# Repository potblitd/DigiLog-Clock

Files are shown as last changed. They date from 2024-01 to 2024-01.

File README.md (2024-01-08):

<p align="center">
  
</p>

## Concept
There a quite a few articles about electronic projects using a grid arrangement of multiple analog clocks to form a mechanical digital clock such as [this one](http://hackaday.io/project/163582-digital-clock-made-of-analog-clocks). Even though they are visually pleasing with numerous rotating pointers and are definitely interesting engineering projects, these clocks require a lot of dual shaft stepper motors to display just one single number. Also, the use of such an arrangement doesn't allow a clean representation of all the 7-segements digits and the pointers that are not used for particular time displays will be hanging around leaving visible lines at random places. The *Concept* part describes the design and movement sequence of my own version of a digital clock composed by multiple analog clocks.

<p align="center">
  
</p>

### Idea
The main goal is to first design an interface with the fewest single-shaft rotating axes to properly display all 7-segment digits and then, to elaborate the most effective rotations sequence to create a counter. Before getting into the design part of the display, a few considerations need to be set based on the future electronic implementation part of this project.
+ For cost saving and program simplification, each axis will have **one rotating element**
+ Located on the same physical plane, the pointers can **not collide or overlap** with each other
+ Driven by servo motors, the rotating elements have a maximum of **180 degrees range**
<!--
<p align="center"> 
  <img src="images/DigiLog-design.svg" width="300" />
</p>
-->
### Design
First of all, to hide out-sticking pointers, the surrounding space outside the digit display will be covered. As the digital clock is displayed by rotating pointers, it is clear that one end of each segment should be attached to an axis. In this way, the arrangement with the least rotating elements that also meets the requirements set above is sketched below. Each element and its possibles position have been given a code combination to facilitate the movements sequence design and coding.
<!-- 
<p align="center">
   <img src="images/axes.svg" width="400" /> <br/><br/>
   <img src="images/digits.svg" width="600" />
</p>

 By observing the digits 0 to 9, an overview can be obtained of which segments are present for each number, their combinations and transitions. Having only 180 degrees angle of rotation available, three 90-degrees spaced positions have to be defined for each axis. The initial positions are already given from the 8 digit. For the blue pointers, a position completely outside the digit display is needed for a 1 and the one in between, covering the top horizontal segment, for a 2. Similarly from numbers 2 and 4, the rotation range for the green elements can be determined. This is further verified by the fact that both pointers never have to go outside the digit display to compose all the numbers. Digit 1 indicates that the yellow pointer needs one position outside the display and the upper left vertical segment for 0. The remaining two purple positions are simply found from any digits in the sequence. The space coverage for each element and their 3 possible positions are illustrated in the figures below. A label is given to each rotating point as well their positions in order to facilitate notations in the next section. -->

<p align="center">
   <br/><br/>
  
</p>

### Sequence
With the code name for each digit representation, the transition movements between them can are written down. For a conventional clock, transitions for counting up and displaying digit 0 from any number and to any number from 0 must be considered. Sometimes, not all the rotating elements can perform the necessary movements simultaneously due to possible collisions of two pointers. In this case, the rotations are executed consecutively in the shortest possible timeframe. 

<p align="center">
  
  &nbsp;&nbsp;&nbsp;&nbsp;&nbsp;&nbsp;&nbsp;&nbsp;&nbsp;&nbsp;
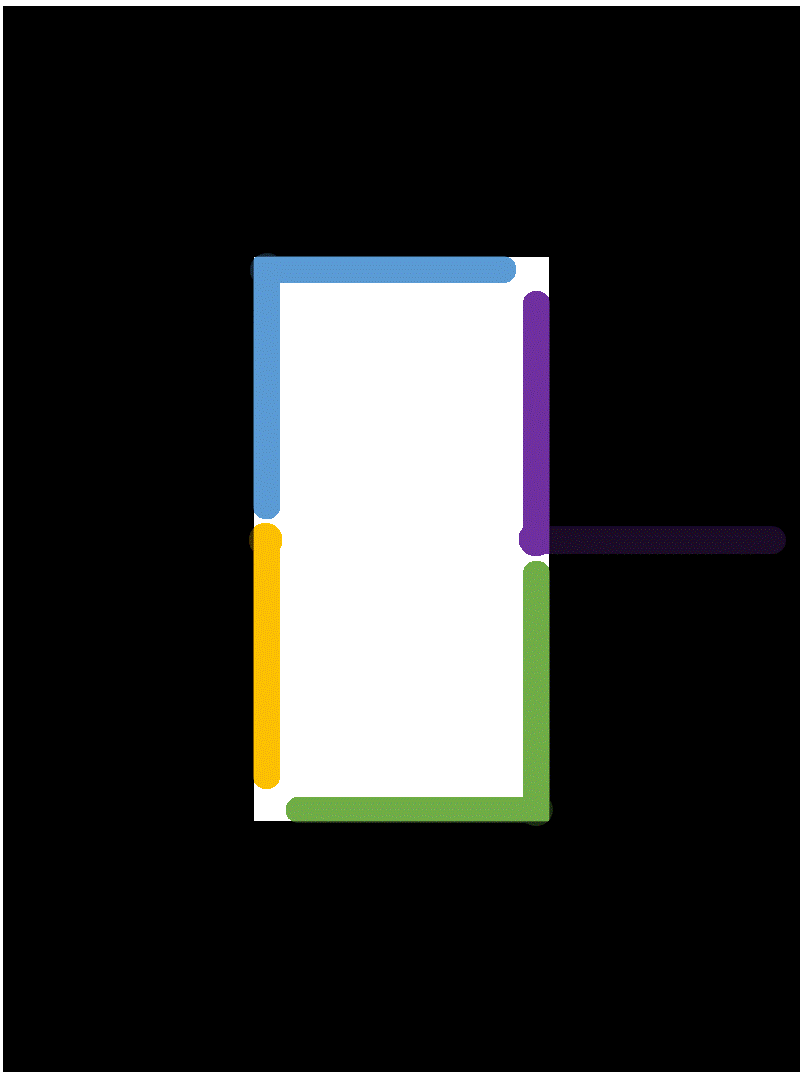
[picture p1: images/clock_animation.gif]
  
</p>

## Implementation
### Components
For the electronic part, which basically controls the movements of the rotating elements, almost only breakout modules are used in order to keep the assembly and programming simple. The main components for one display are listed below.
+ 4 x SG90 servo motor
+ PCA9685 PWM driver
+ 5V2A DC power supply
+ ESP8266 D1 mini dev board
+ DS3231 RTC module

<p align="center">
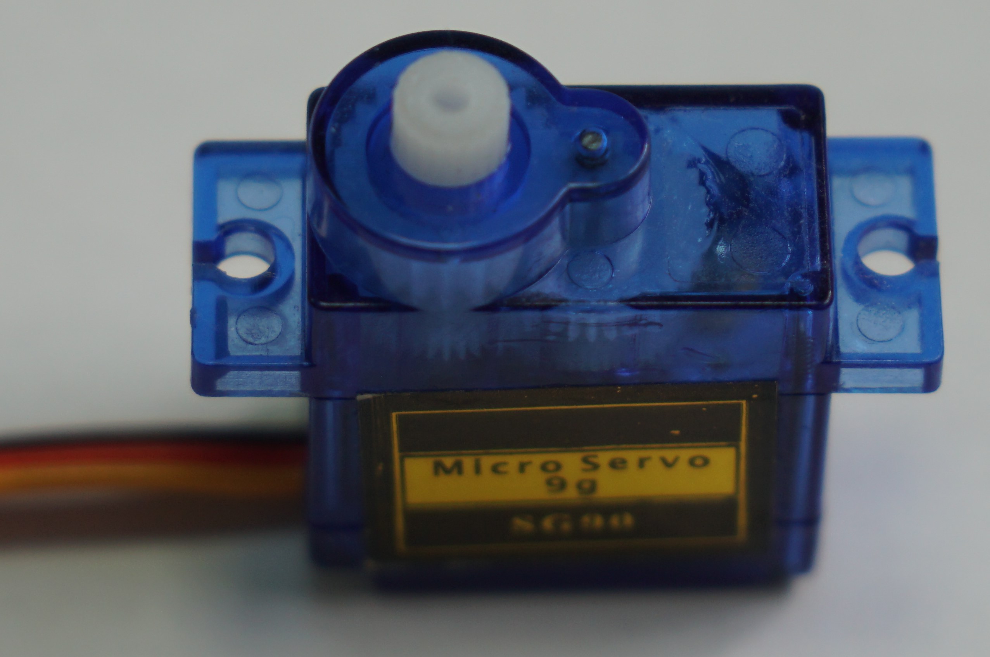
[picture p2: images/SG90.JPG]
  
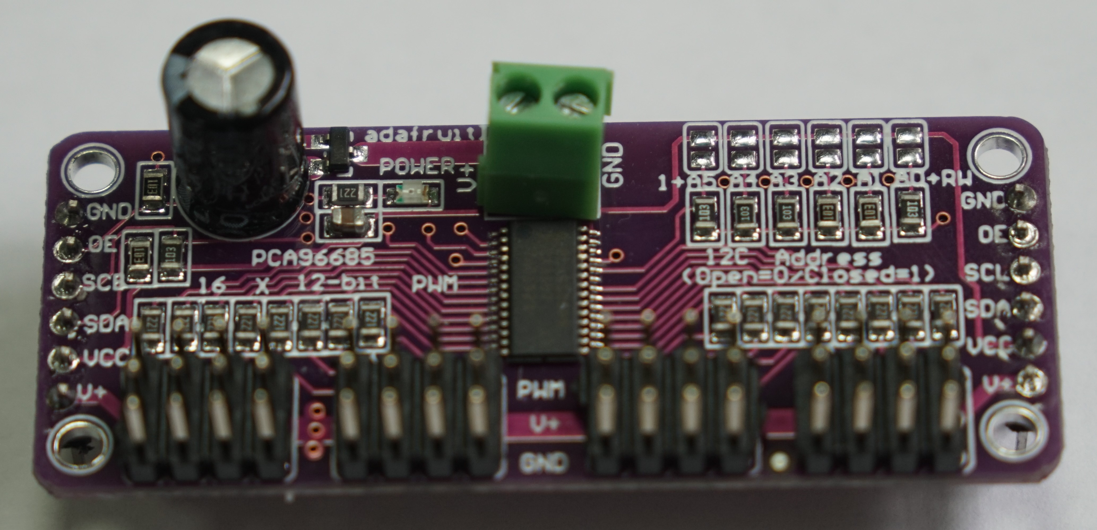
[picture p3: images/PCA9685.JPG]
  
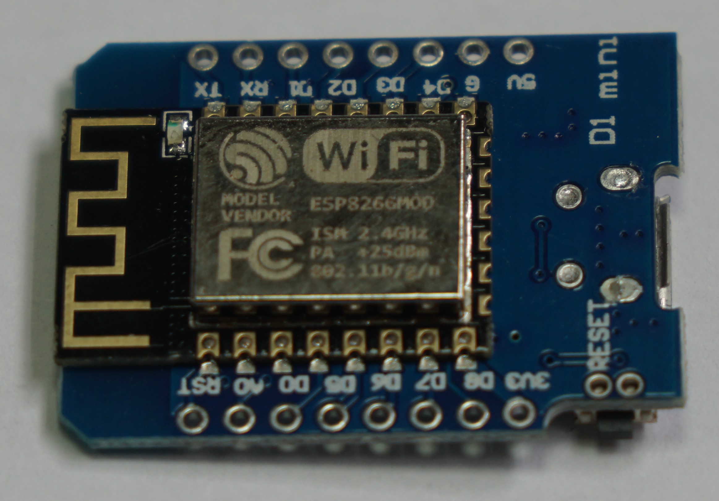
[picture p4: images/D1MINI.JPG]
  
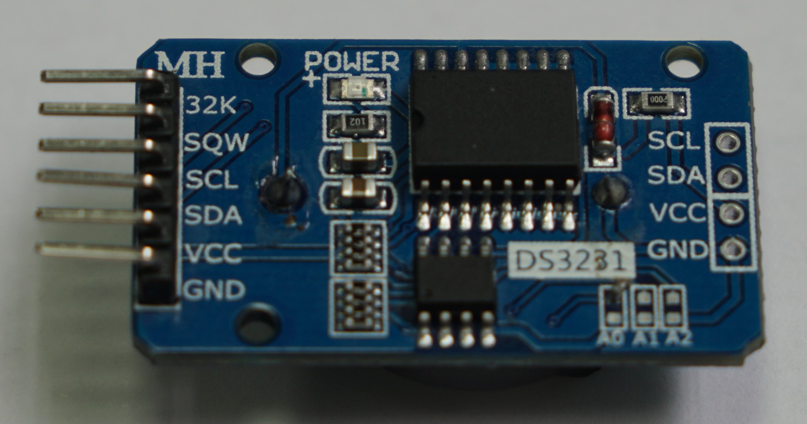
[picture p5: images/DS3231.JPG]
  
</p>

The commonly used SG90 servo motor is chosen for this project as it is small, light and cheap. The torque has no particular importance here but its angular speed, which is about 0.15s/90 degrees, is crucial to make sure a digit transition is possible every second. In order to drive multiple of these SG90s simultaneously, a PCA9685 16-Channel Servo/PWM driver is used. It provides the current-demanding motors with separated 5V from the external DC power supply and is controlled through an I2C interface which is communicated from the D1 mini. Finally, a real time clock module is included in the system to achieve good time accuracy.

### Schematics
The servo motors consuming lots of current, their voltage is provided through a barrel connector with the external 5V DC power supply cable. The presence of this voltage is indicated by a blue LED. If, additionally the USB cable is connected to the D1 mini, i.e. for programming the ESP8266, the switch should be positioned accordingly. In either case, VCC of 3.3 volts is generated by the internal LDO of the D1 mini and is indicated by a yellow LED. <br/>
The D1 mini microcontroller communicates with both the PWM driver and the real-time clock through an I2C interface. Four push buttons, used for start & stop, reset and setting the time, are connected to the GPIO pins D5, D6 and D7 which are pulled high internally, and D8 which is pulled low on the ESP8266 module board. If more than 16 servo motors are used in a setup, another PCA9685 driver can be connected via the additional pin headers P1 or P2. 

<p align="center">
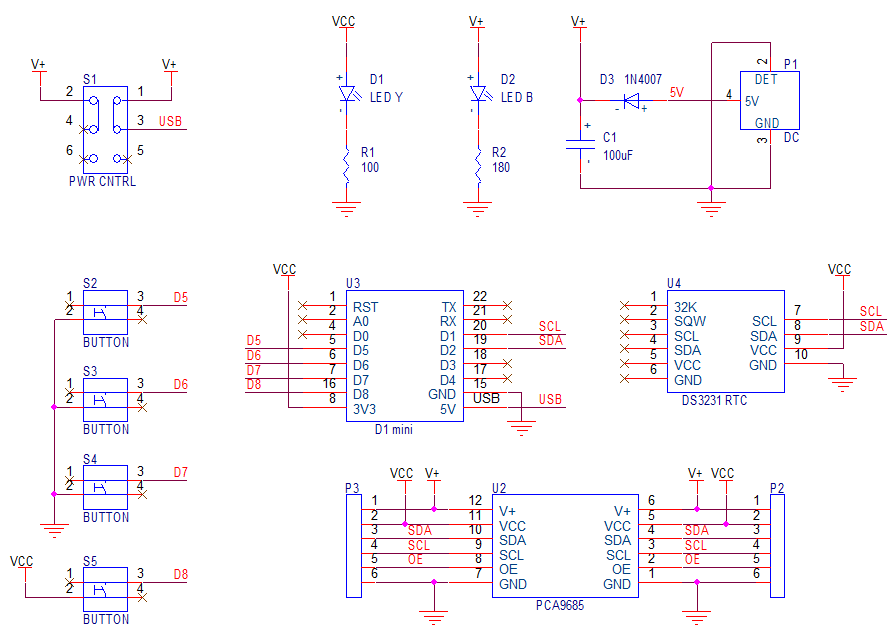
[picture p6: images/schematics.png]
  
</p>

### PCB
The PCB has the same size as the assembly outline so it can be fixed to the mounting plates with M3 standoffs. All the components are installed on the top layer of the board. It is also possible to solder the switch, button and LEDs on the bottom layer for a different mounting configuration. Modules D1 mini, DS3231 RTC and PCA9685 PWM driver are simply plugged into their corresponding female pin headers so that they can be removed or inserted easily.

<p align="center">
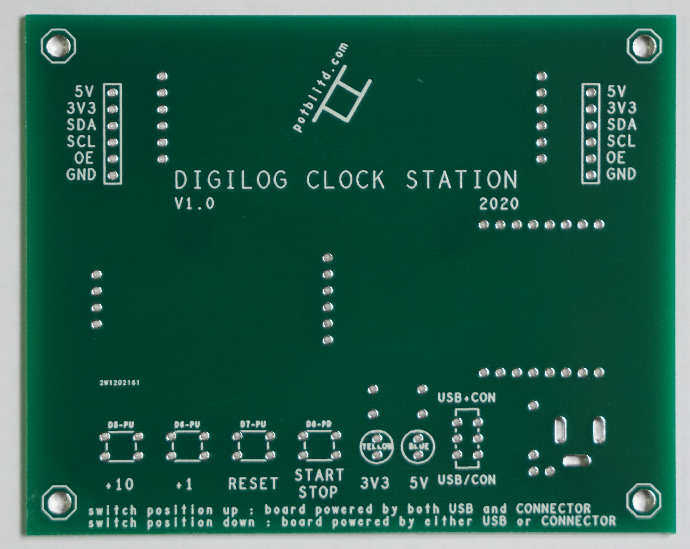
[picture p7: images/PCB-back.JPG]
  
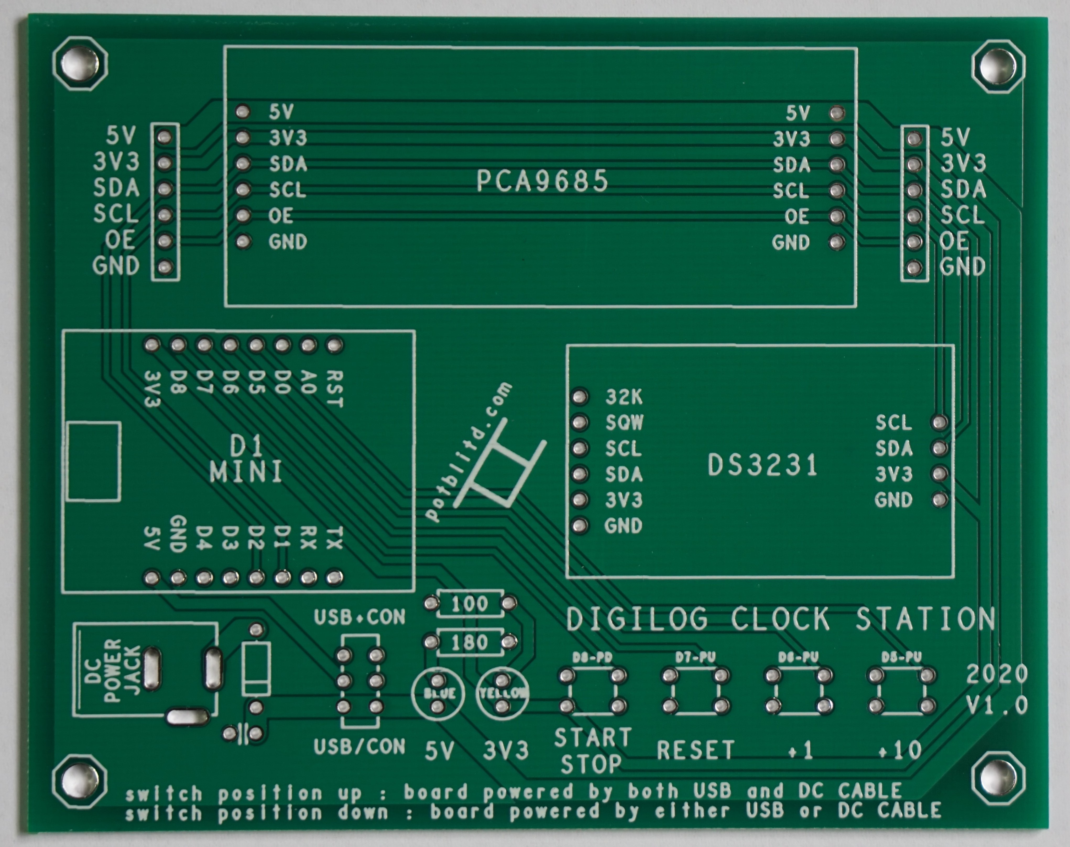
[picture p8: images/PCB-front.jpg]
  
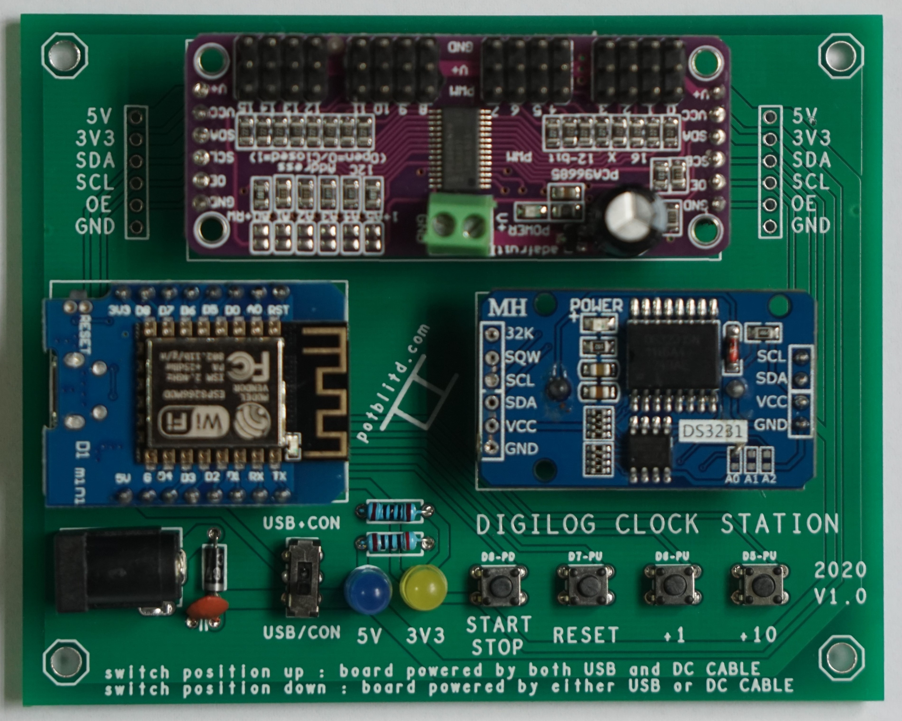
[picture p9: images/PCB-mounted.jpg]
  
</p>

### Display
In the [Concept](#concept) section, the arrangement of the rotating axes has already been established. Now, the positions of the servo motors are determined so as to set the smallest distance between their shafts. For this, they are tilted at 45 degrees separating their interaxial distance by 20 mm. In this configuration, multiple single digits can be arranged next to each other to form an hour-minute-second clock. <br>
For this project, the prototype assembly incorporates 8 servos allowing the composition of 2 digits. The outline dimensions are chosen so that the rotating pointers should never exceed the border. Both displays are placed 20 mm apart to avoid interfering each other. This results in an outline size of 100 mm by 80 mm. To hide the pointers turning outside of the digit display, a front plate is placed on top.

<p align="center">
  
</p>

### Mechanical parts
The mechanical parts for the assembly were designed in [Tinkercad](https://www.tinkercad.com/). One plate is used to precisely mount the 8 servo motors and another plate as the front cover. Both plates can be held together by fixing M3 screws in the corners. For the design of the rotating elements, the left pointers had to be higher than the right ones because they overlap with each other in the space between the digit displays.

<p align="center">
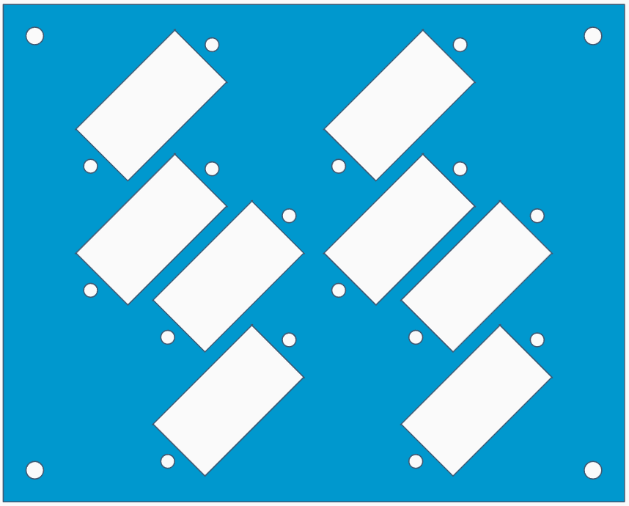
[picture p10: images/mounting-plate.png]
  
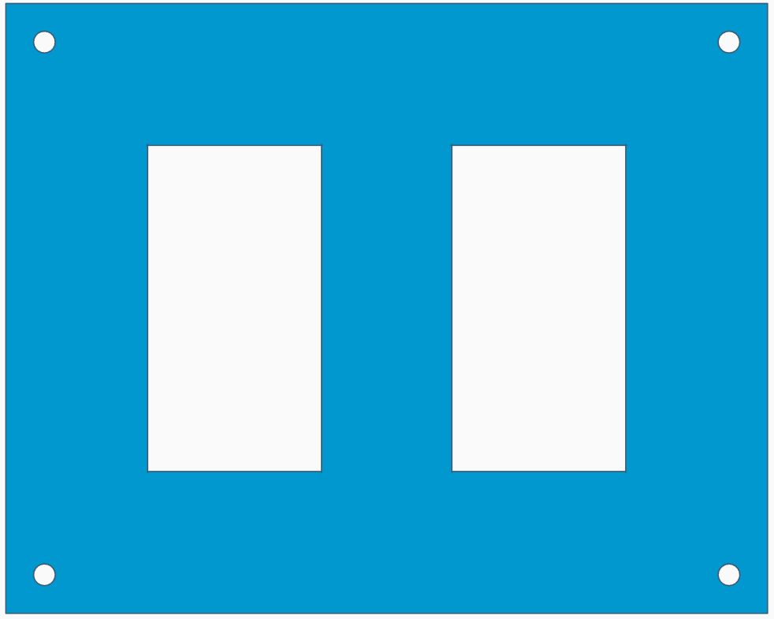
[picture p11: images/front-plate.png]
  
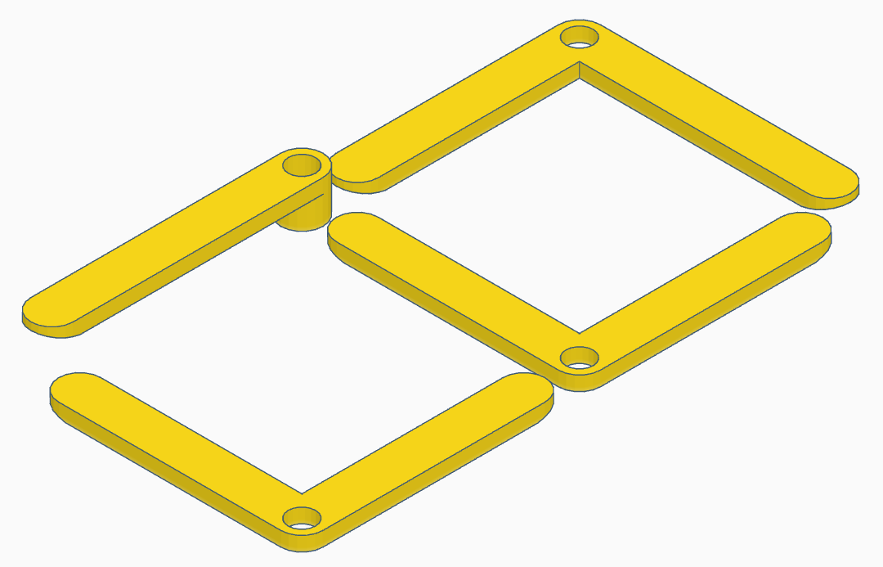
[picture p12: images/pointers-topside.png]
  
  <!-- <img src="images/assembly.png" height="200" /> -->
  <!--  <img src="images/assembly-side.png" height="150" /> -->
  <!-- <img src="images/assembly-front.png" height="200" /> -->
</p>

### Assembly
The 8 servo motors are inserted into their respective holes in the mounting plate and are fixed with small M2 screws. Then, the pointers can be positioned on the turning gear of the servos by sliding them on like a hat. This design is not exactly fitting so the pointers are not perfectly aligned with each other. After soldering all the components to the PCB, it is mounted onto the plates. In this configuration, the PCB is facing outwards where the SG90 cables go around the edges to connect into the PWM driver. By turning the PCB inwards, the connection cables stay inside the border outline, forming a more compact and closed assembly.

<p align="center">
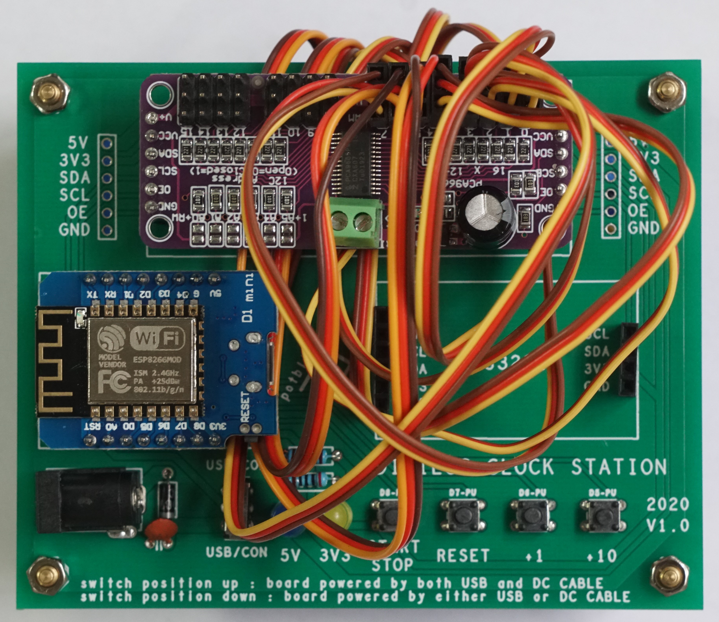
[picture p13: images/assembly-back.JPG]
  
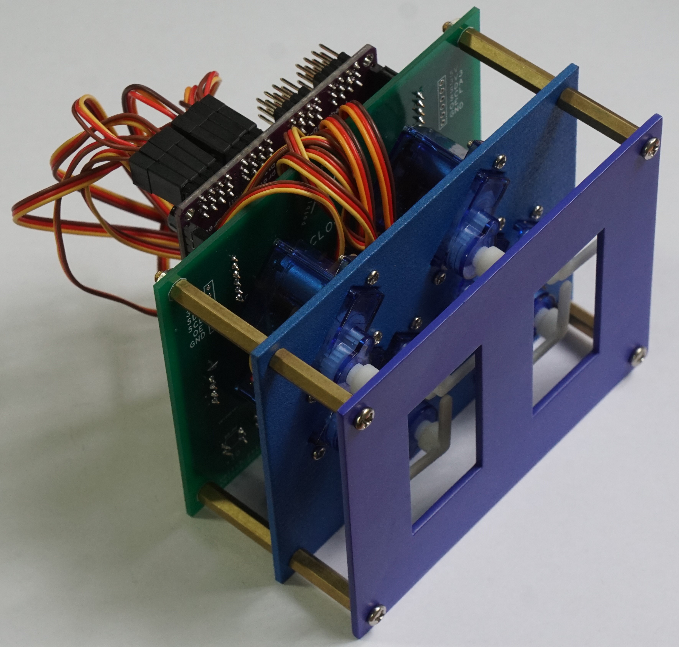
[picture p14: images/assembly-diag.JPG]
  
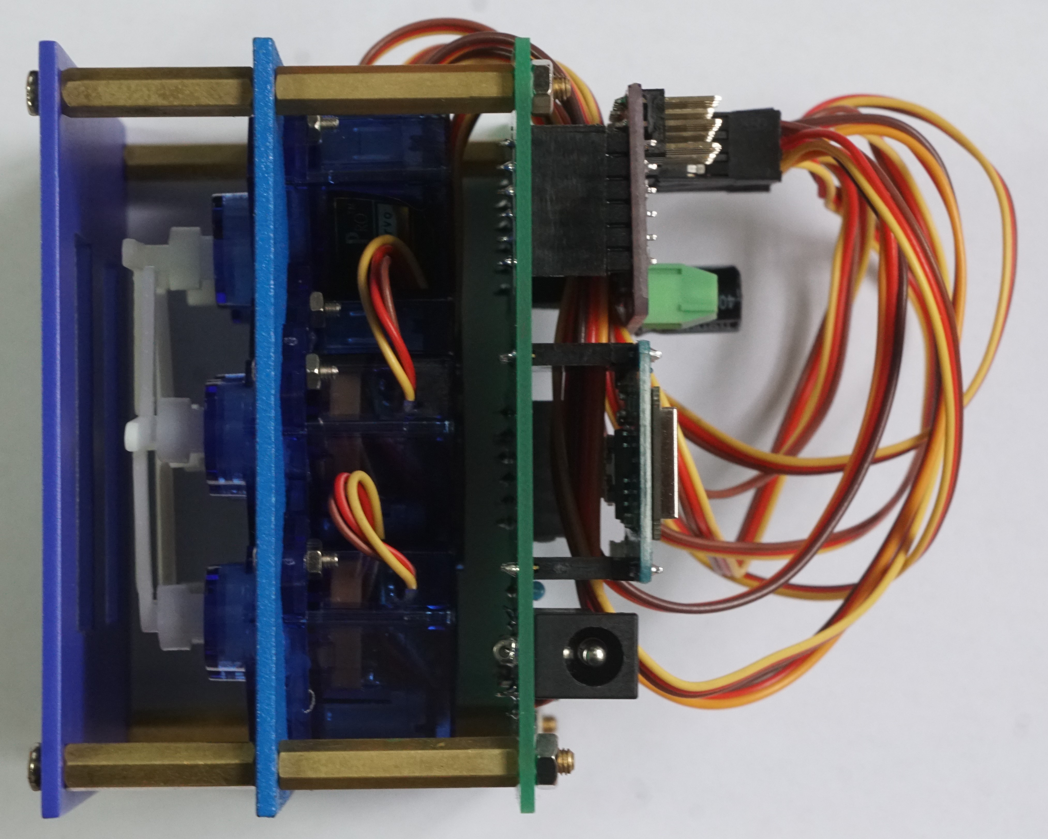
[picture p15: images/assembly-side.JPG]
  
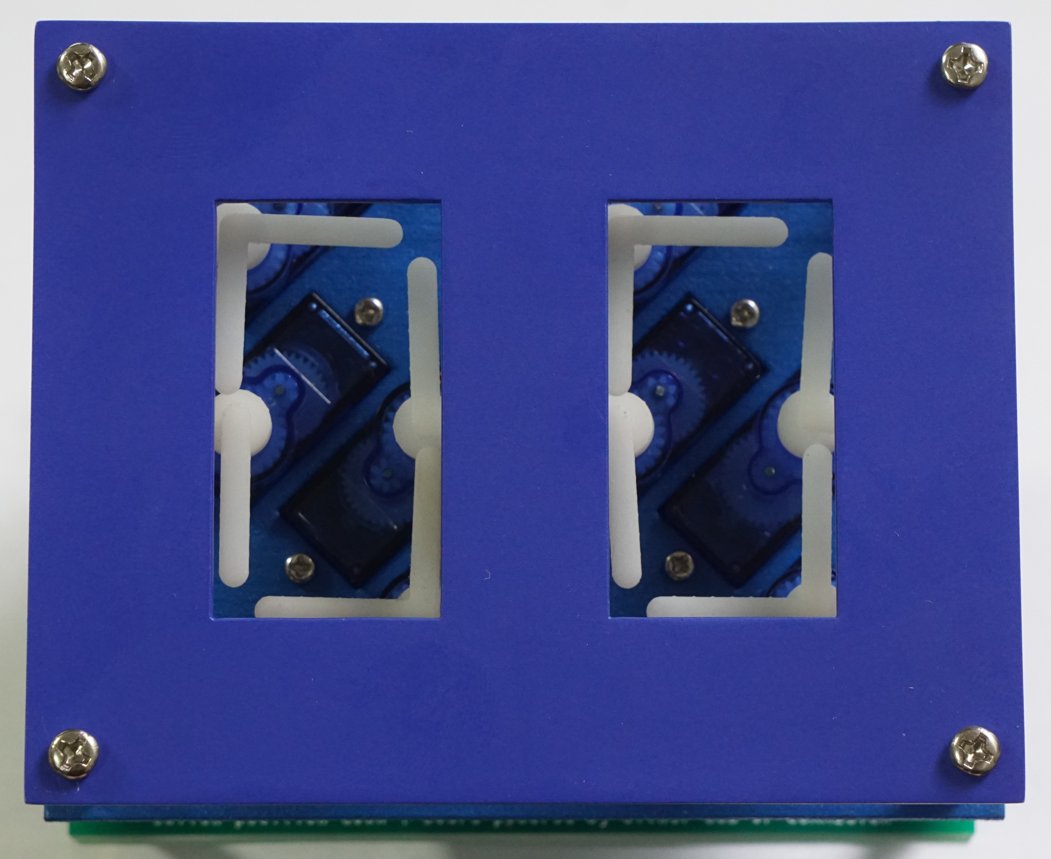
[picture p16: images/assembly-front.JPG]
  
</p>

### Code
In the Arduino program, the positions for each rotating element is configured so that they align as straight as possible. Due to some fabrication inaccuracies and angle precision limitations, not all the pointers could be smoothly aligned here. For the rest of the code, each transition is defined by the current digit and the next one based on the [sequence](#sequence). The D1 mini checks the current time from the DS3231 RTC and updates the digits on the display.

<p align="center">
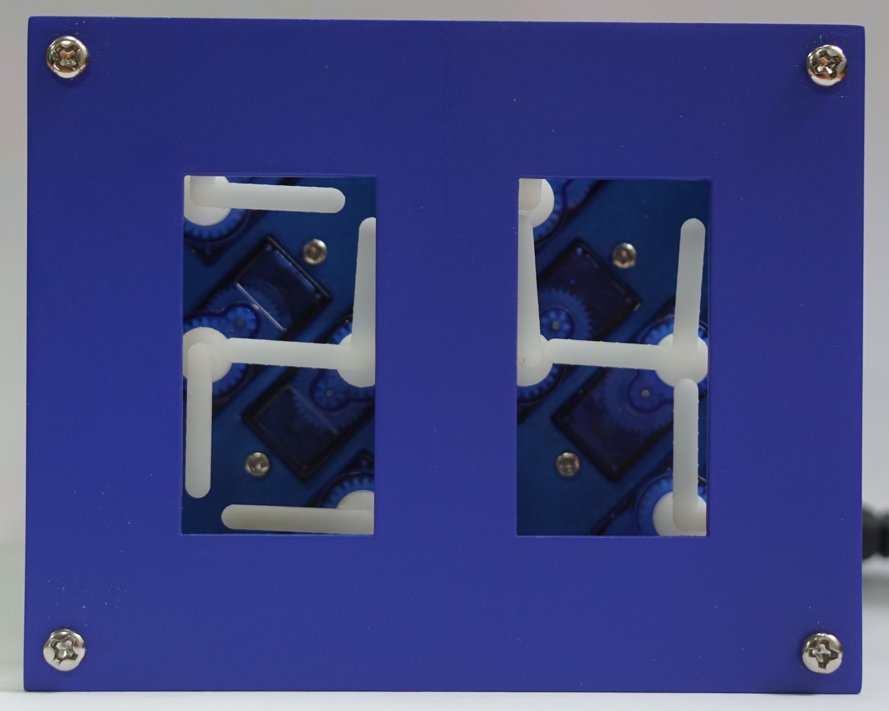
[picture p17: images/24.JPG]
  
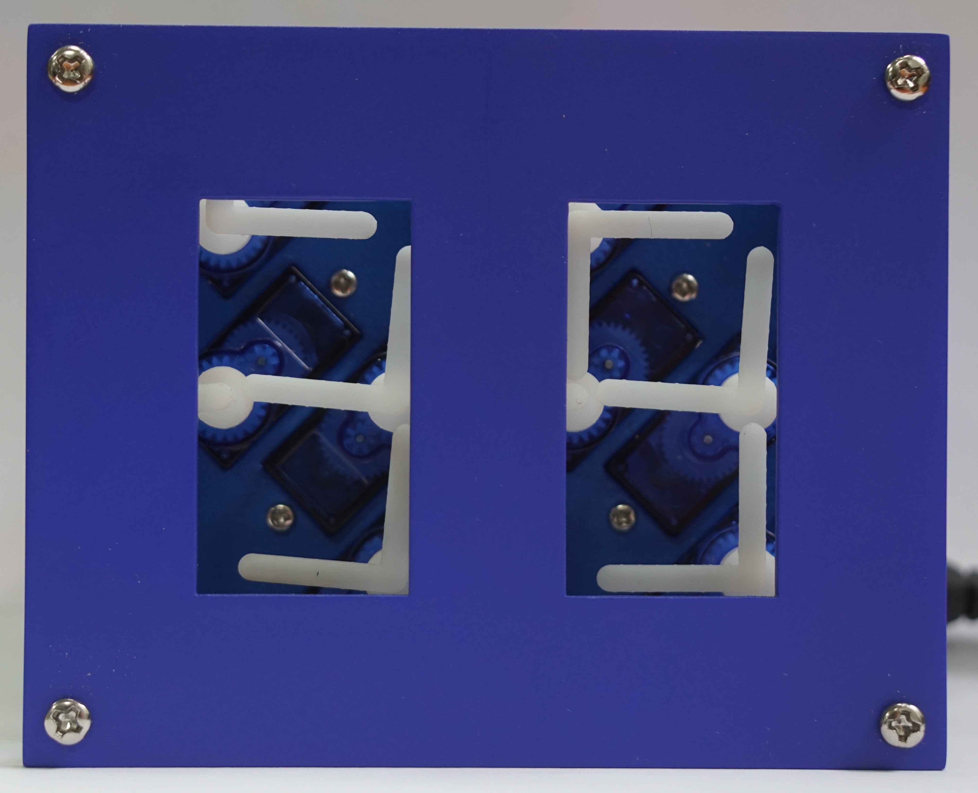
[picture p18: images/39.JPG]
  
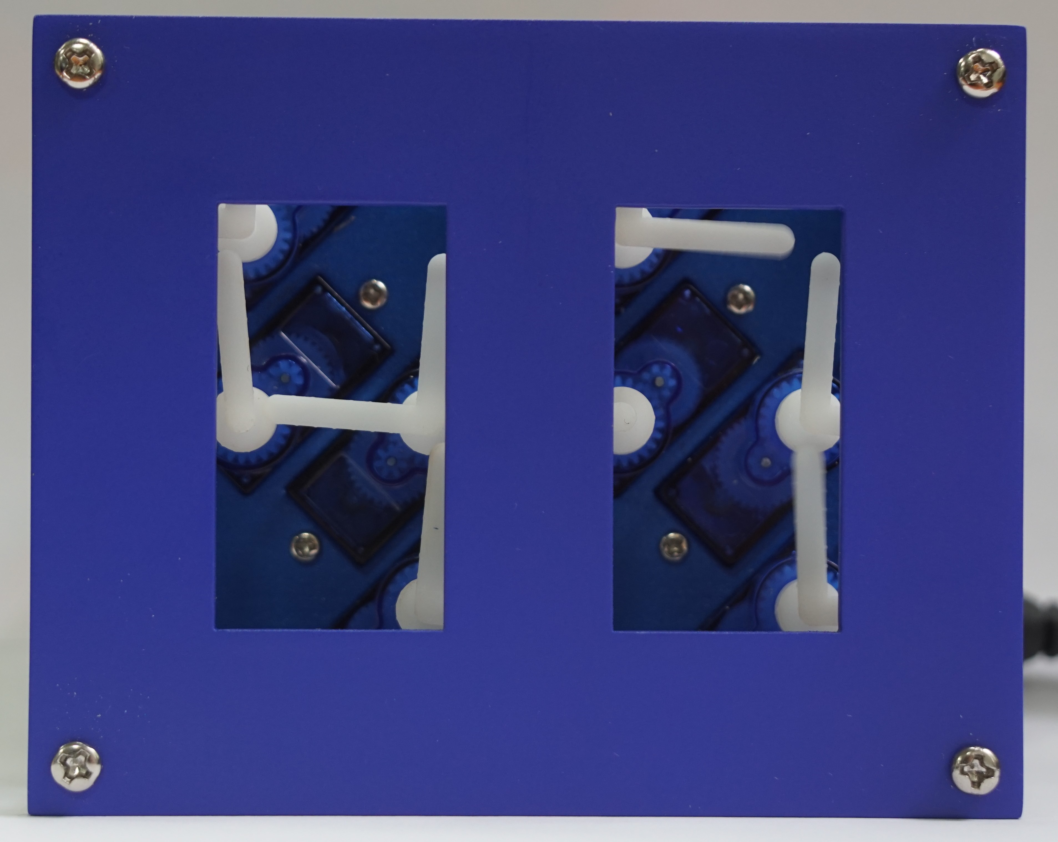
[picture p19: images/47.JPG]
  
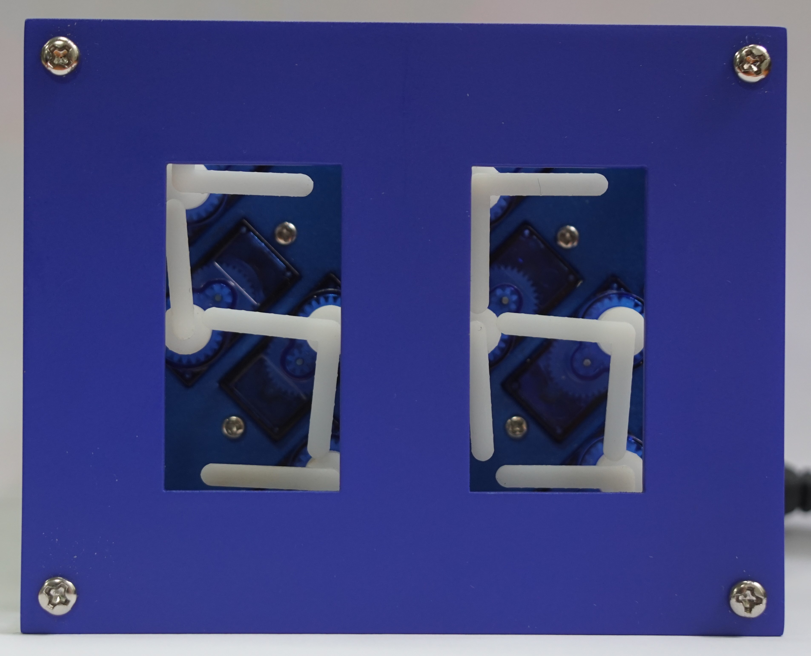
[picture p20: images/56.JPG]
  
</p>

### Cost
Electronic parts, i.e. PCB, modules, components to solder and servo motors costed about 80 RMB. The 3D printed mechanical parts with mounting screws and standoffs were 285 RMB altogether which gives a total price of 365 RMB (51.39 USD).

### Future improvements
The prototype assembly accomplishes its proof-of-concept perfectly fine, the servo transitions are fast and precise enough to beautifully display digits without collisions between pointers. However, there a few improvements to note for the code or for a future version.
+ To actually act as a clock and display the time, there should be at least 4 digits for minutes and hours. Having another pair of digits for the seconds could also be considered but each servo movement is noisy and can be bothering. Up to 16 servos can be driven by the PCA9685 and so, one PCB is sufficient.
+ The corners of the mechanical plates can be rounded to cover only the rotating pointers and thus reducing the size. This would also give the clock a better aesthetic.
+ Reading the digits requires a direct line of sight on the assembly because the front plate can hide the pointers when observing the clock from an angle. This can easily be corrected by mounting the front plate as close as possible to the pointers.
+ The four buttons on the back of the PCB could be implemented to add other features such as manual time setting, stopwatch, button-press counter or days/hours down-counter.
+ With the on-board ESP8266 WiFi chip, the clock could display live number fetched from the internet or from another device, such as a weather station.
+ Use laser cutting for the fabrication of the mechanical parts to reduce costs and get better accuracy.

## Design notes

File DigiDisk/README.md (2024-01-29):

<p align="center">
  
</p>

### Idea
This updated version of the DigiLog clock, called 'DigiDisk', is meant to improve the previous design but also change a few aspects to meet the following requirements :

+ Use cheap and easily available components
+ Simple setup with as little parts as possible
+ Full clock, meaning at least 4 digits
+ Use overlapping disks to avoid collision of sharp edges and accelerate digit transitions
+ Ditch the WiFi, embrace minimal MCUs
+ Fully assembled PCB (no modules)
+ Finish version, no more ugly prototypes
+ USB type-C power and programming

### Design
Having overlapping disks with marked pointers instead of bar elements involved changing the 4 axes positions and pointers arrangement, and set the disk layer order to draw all 10 digits. With the code names, each digit can be defined by its disks positions. Since the rotating elements are overlapping each other, there is no need to plan the sequence diagram as done for the first version. This significantly simplifies the coding parts later on.

<p align="center">
   <br/><br/>
  
  &nbsp;&nbsp;&nbsp;&nbsp;&nbsp;
  
</p>

### Components
The servo motors are driver by the PCA9685 PWM controller used previously and the time is fetched from the common PCF8563 real-time clock. As the microcontroller of the system only needs to write and read with the two other chips through I2C, the ATtiny402 is very suitable (and my fav). The servo motors have been upgraded to the MG90S as they are less noisy and their motion is more smooth and precise without a dramatic price increase. For programming the ATtiny over USB, the CH340C is added as it has a simple footprint (SOP-16) and does not require an external oscillator. 

+ ATtiny402 microcontroller
+ CH340C USB to serial
+ PCF8563 real-time clock
+ PCA9685 PWM driver
+ 16 x MG90S servo motor

### Schematics
The system is powered through a USB-C port (on a breakout board) and its status is indicated by a blue LED. For the 16 servo motors, the power supply must be able to provide at least 18W. Programming the ATtiny402 is accomplished through the CH340C chip with the schottky diode between RX and TX to allow UPDI. Somehow, this setup works even without the pull-down resistors on the CC signals, which reduces components and extra connections. The RTC chip has a CR1220 coin cell as an auxilliary power source to keep the time running while unplugged from the USB-C connector. As only one PCA9685 driver is required, its i2C address is hardwired to the default value. 

<p align="center">
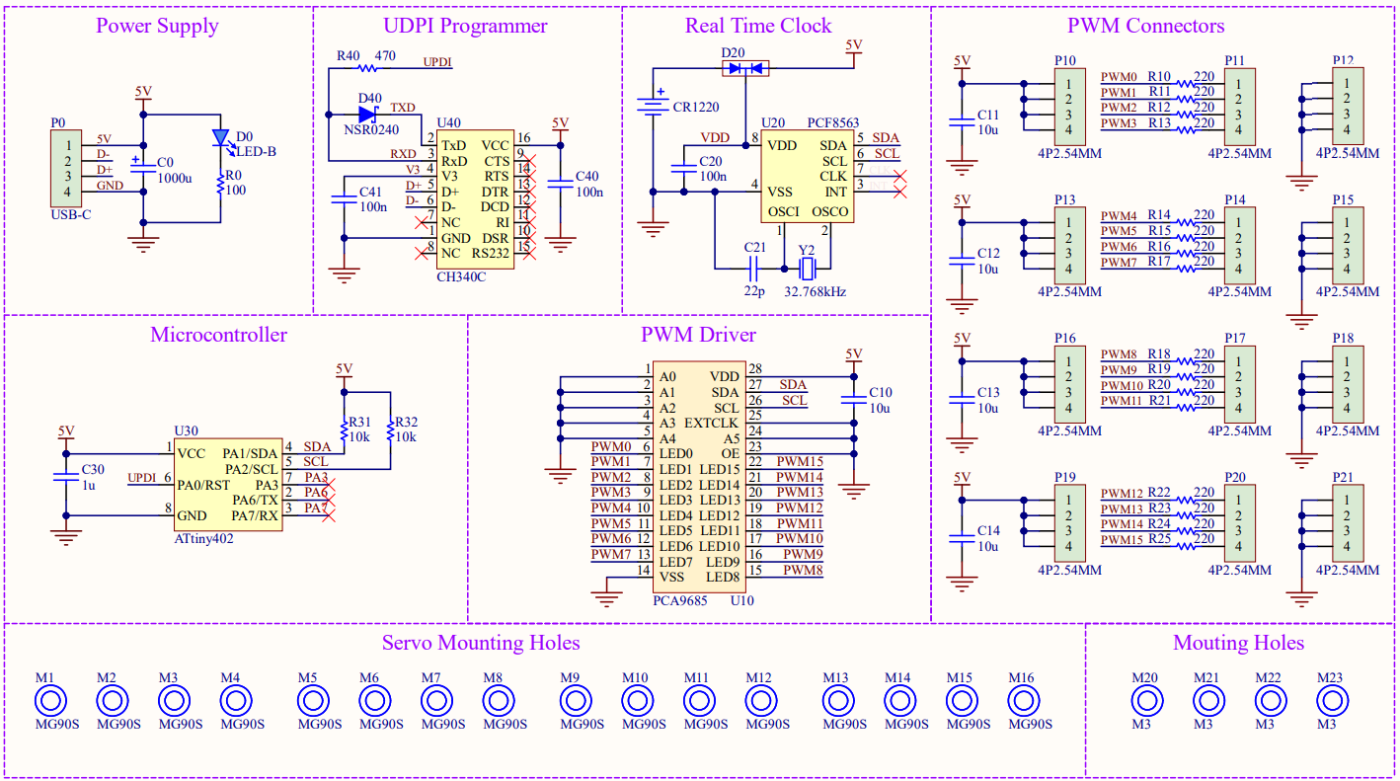
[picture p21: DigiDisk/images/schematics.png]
  
</p>

### Display
With the axes position slightly changed from the previous version, the servo also needed to be adjusted but the idea remains the same. In this configuration, two digits must be separated by at least 20mm. The front plate covers the unwanted pointers.  

<p align="center">
  <br/><br/>
  
</p>

### PCB
The board not only integrates all the electronic components, but also includes the mounting holes for the servo motors. In this way, no additonal mounting plates must be manufactured. The outline of the PCB is 80mm high by 180mm wide.

<p align="center">
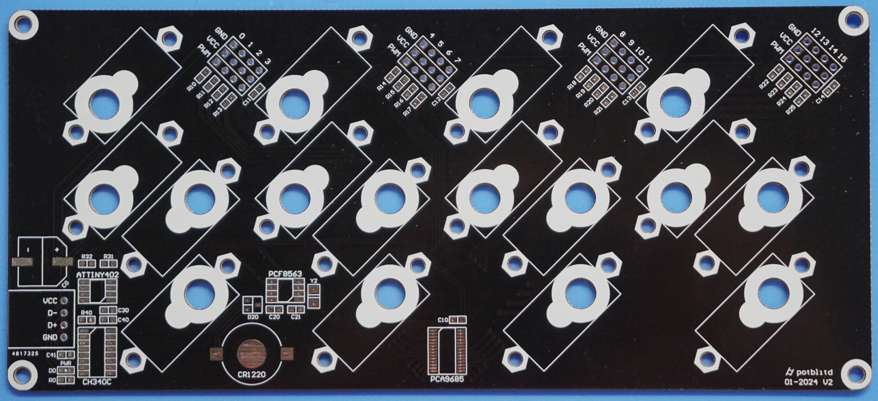
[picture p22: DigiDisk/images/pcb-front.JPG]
  
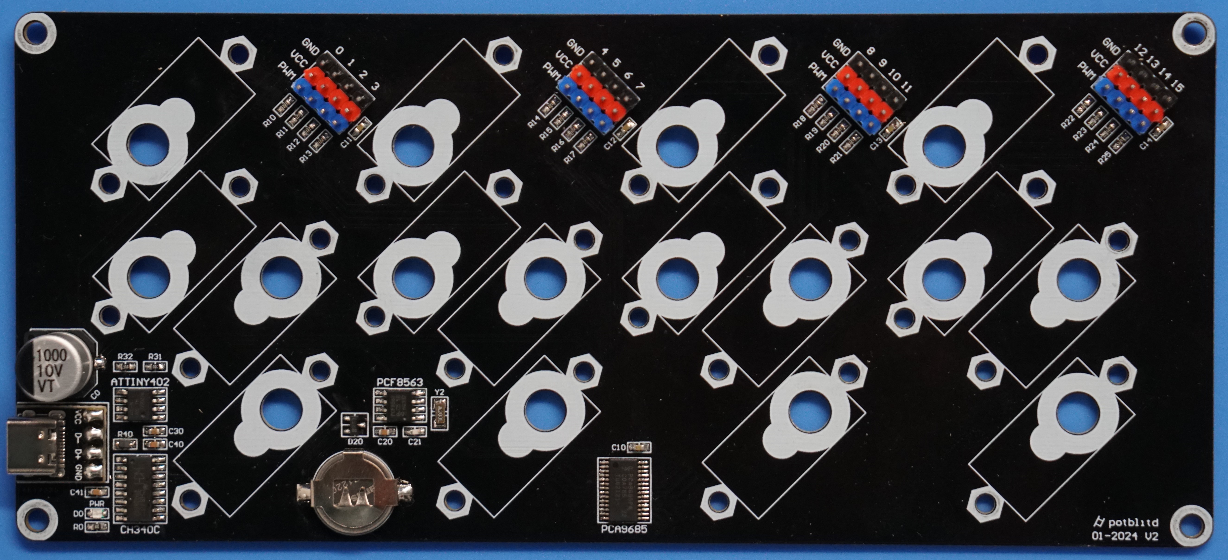
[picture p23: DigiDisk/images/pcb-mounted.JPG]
  
</p>

### Mechanical parts
Since the PCB acts as the mounting plate, only the rotating disks and the front plate must be manufactured. The disks are actually made from thin PCBs with silkscreen pointers as the thickness and material is very suitable. For the front plate, a 1mm PVC board was cut and painted black.

<p align="center">
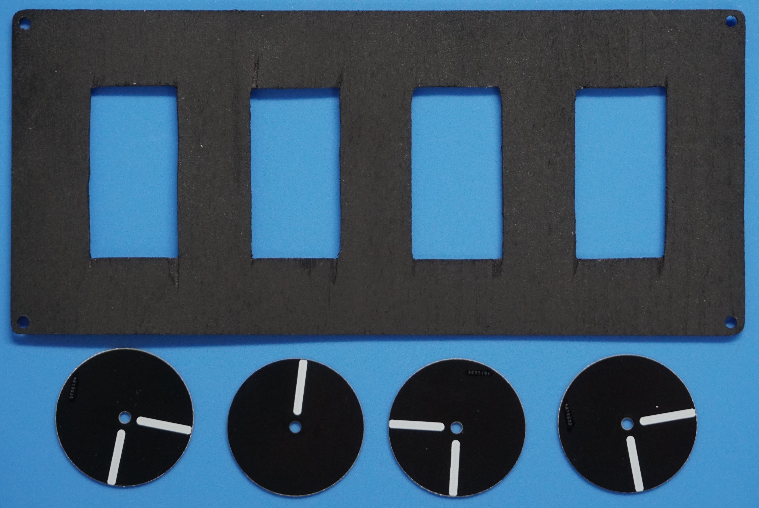
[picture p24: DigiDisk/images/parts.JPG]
  
</p>

### Assembly
All 16 servo motors are mounted to the base PCB with 9mm spacers and long screws. The precise mounting of the servos is crucial to avoid the rotating disks rubbing each other. With 0.8mm thick PCBs for the disks, they are overlaying each other through 1mm spacers, keeping the total height only a little over 5mm. The front plate not being perfectly falt, is mounted on top of the base PCB with 6mm spacers in the corners. 

<p align="center">
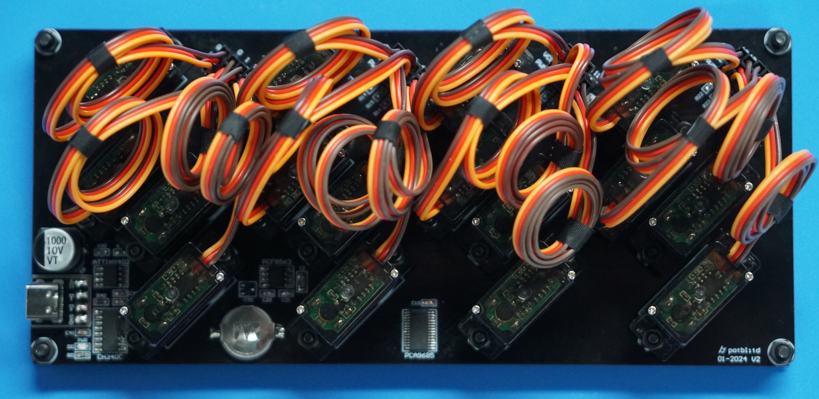
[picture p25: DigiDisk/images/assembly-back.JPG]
  
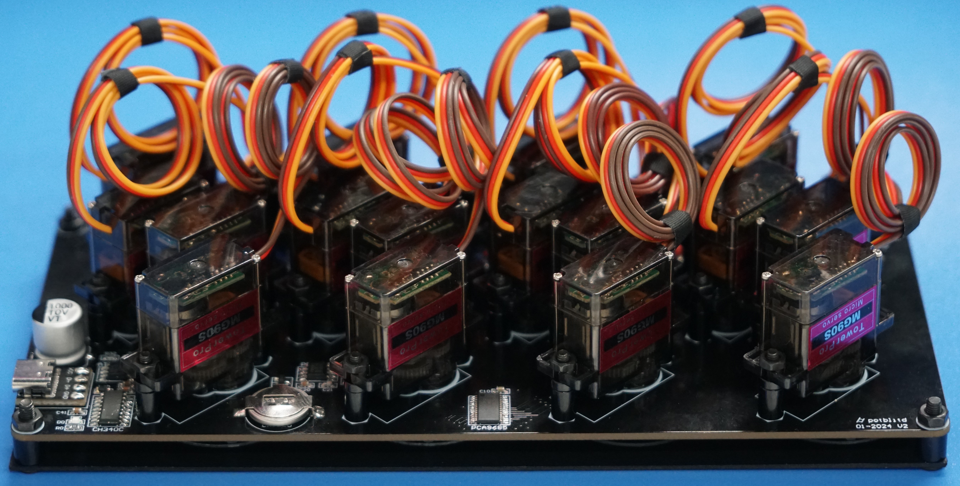
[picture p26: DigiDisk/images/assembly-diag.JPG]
  
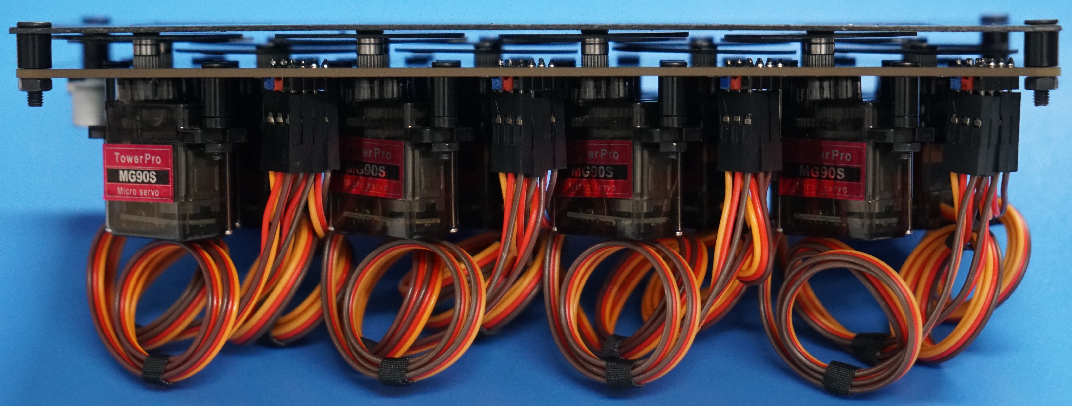
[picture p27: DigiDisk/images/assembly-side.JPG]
  
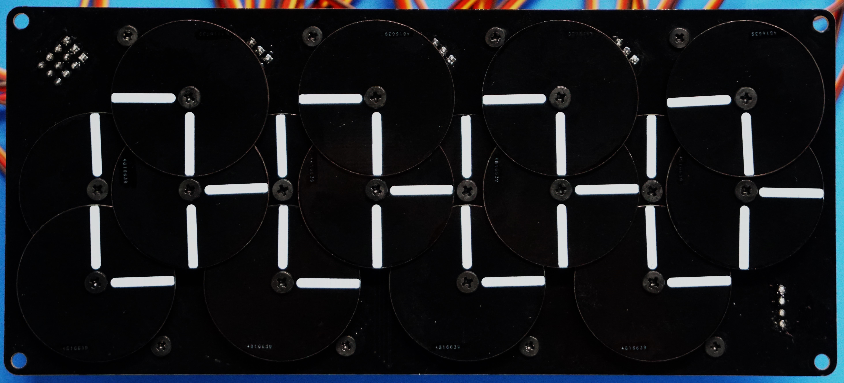
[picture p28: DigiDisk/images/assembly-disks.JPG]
  
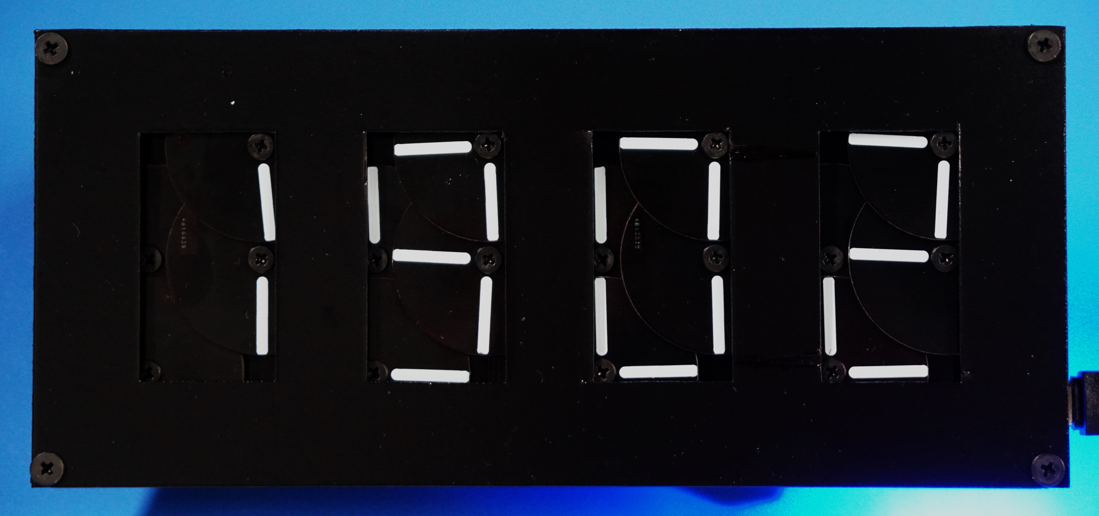
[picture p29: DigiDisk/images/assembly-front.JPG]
  
</p>

### Code
The code, written in Arduino, uses librairies [PCA9685](https://github.com/NachtRaveVL/PCA9685-Arduino) and [Rtc_Pcf8563](https://github.com/orbitalair/Rtc_Pcf8563/tree/master). The PWM value for each disk position is established and then, the _set_digit_ function defines the 4 disk positions for every number. In the _setup_ section, the PWM frequency is set and all digits are set to display 0. During the loop, current minute and hour are checked from the real-time clock which are then used to update the digits with the _set_digit_ function.

### Cost
The PCB with all the components costs 50.83 RMB (7.16 USD) and with the 16 servo motors it's 127.31 RMB (17.94 USD). The PCB disks, front plate and all kinds of mounting components come up to 137.62 RMB (19.39 USD). So, the total expenses for this clock are 264.93 RMB (37.33 USD). Since the most expensive items are the PCBs, buying larger quantities would decrease the unit price a lot.

<table>
<tr><th>Electronic parts </th><th>Mechanical parts</th></tr>
<tr><td valign="top">

| Component | Price/unit  | Quantity  | Cost  |
| --- |---:|---:| -----:|
| Base PCB | 30.230 | 1 | 30.23 |
| ATtiny402 | 3.090 | 1 | 3.09  |
| PCF8563 | 2.000 | 1 | 2.00  |
| PCA9685 | 8.630 | 1 | 8.63  |
| CH340C | 1.460 | 1 | 1.46  |
| USB-C breakout | 0.320 | 1 | 0.32  |
| 1000uF capacitor | 0.706 | 1 | 0.71  |
| 0603 capacitor | 0.025 | 10 | 0.25  |
| 0603 resisitor | 0.030 | 20 | 0.60  |
| 0603 LED | 0.015 | 1 | 0.02  |
| FC-135 crystal | 1.700 | 1 | 1.70  |
| BAT721C diode | 0.400 | 1 | 0.40  |
| CR1220 retainer | 0.050 | 1 | 0.05  |
| CR1220 battery | 1.120 | 1 | 1.12  |
| 4P 2.54mm header | 0.022 | 12 | 0.26  |
| MGS90S servo | 4.780 | 1 | 76.48 |
| **Electronic total** | | | **127.31** |

</td><td valign="top">

| Component | Price/unit  | Quantity  | Cost  |
| --- |---:|---:| -----:|
| M2.5*16 servo | 0.121 | 32 | 3.88  |
| 2.7*7 spacer | 0.898 | 32 | 28.74 |
| 2.7*2 spacer | 0.898 | 32 | 28.74 |
| M2.5 nuts | 0.093 | 32 | 2.97  |
| Disk PCB | 3.624 | 16 | 57.98 |
| M2.5*4 disk 1 | 0.070 | 4 | 0.28  |
| M2.5*5 disk 2 | 0.070 | 4 | 0.28  |
| M2.5*6 disk 3 & 4  | 0.074 | 8 | 0.59  |
| 2.6*1 spacer | 0.620 | 8 | 4.96  |
| 2.6*2 spacer | 0.620 | 8 | 4.96  |
| M3*14 front plate  | 0.117 | 4 | 0.47  |
| M3 nuts | 0.060 | 4 | 0.24  |
| 3.1*6 spacer | 0.798 | 4 | 3.19  |
| Front plate board  | 0.332 | 1 | 0.33  |
| **Mechanical total** | | | **137.62** |

</td></tr> </table>

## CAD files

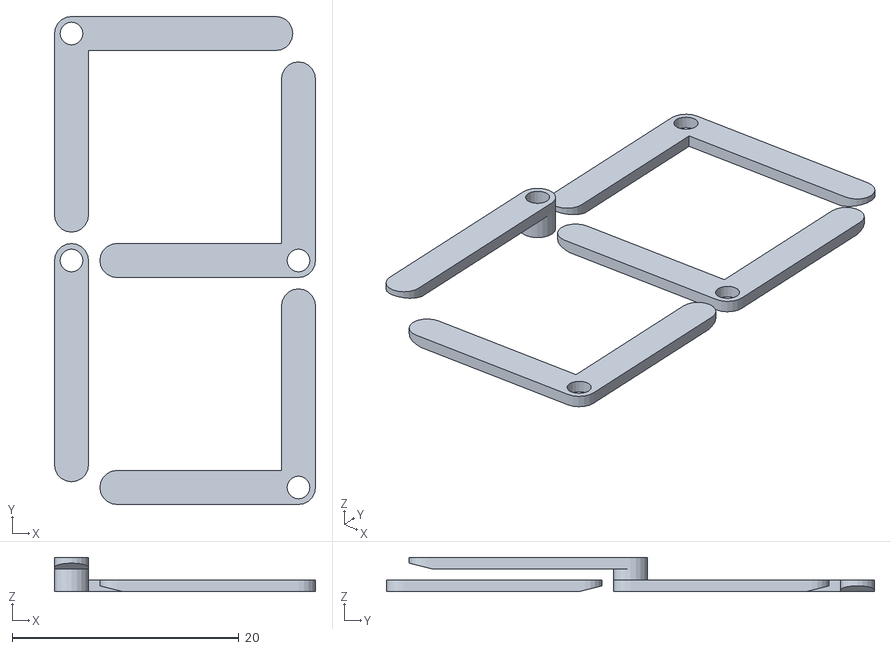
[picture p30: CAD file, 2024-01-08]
3D models/pointers.stl
23.0 x 43.0 x 3.00

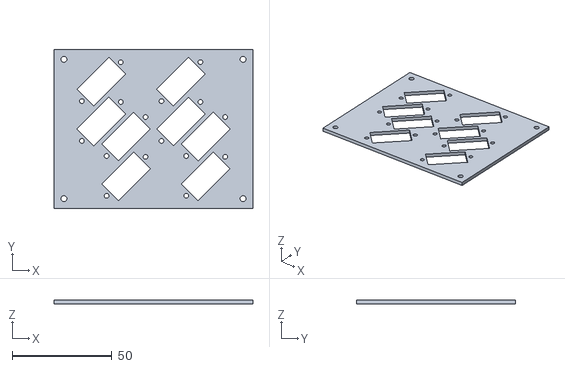
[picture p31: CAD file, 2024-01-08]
3D models/mounting-plate.stl
100.0 x 80.0 x 2.00

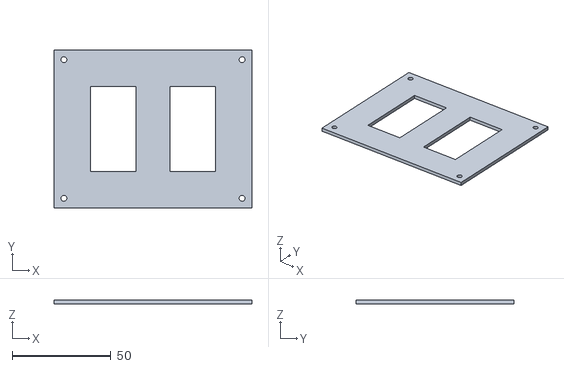
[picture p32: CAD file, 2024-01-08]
3D models/front-plate.stl
100.0 x 80.0 x 2.00

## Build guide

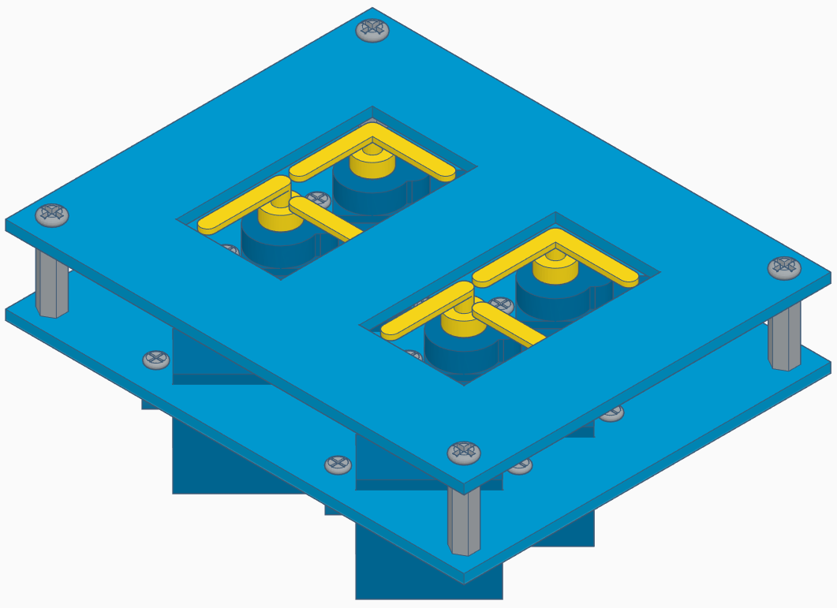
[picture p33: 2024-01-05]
images/assembly-side.png

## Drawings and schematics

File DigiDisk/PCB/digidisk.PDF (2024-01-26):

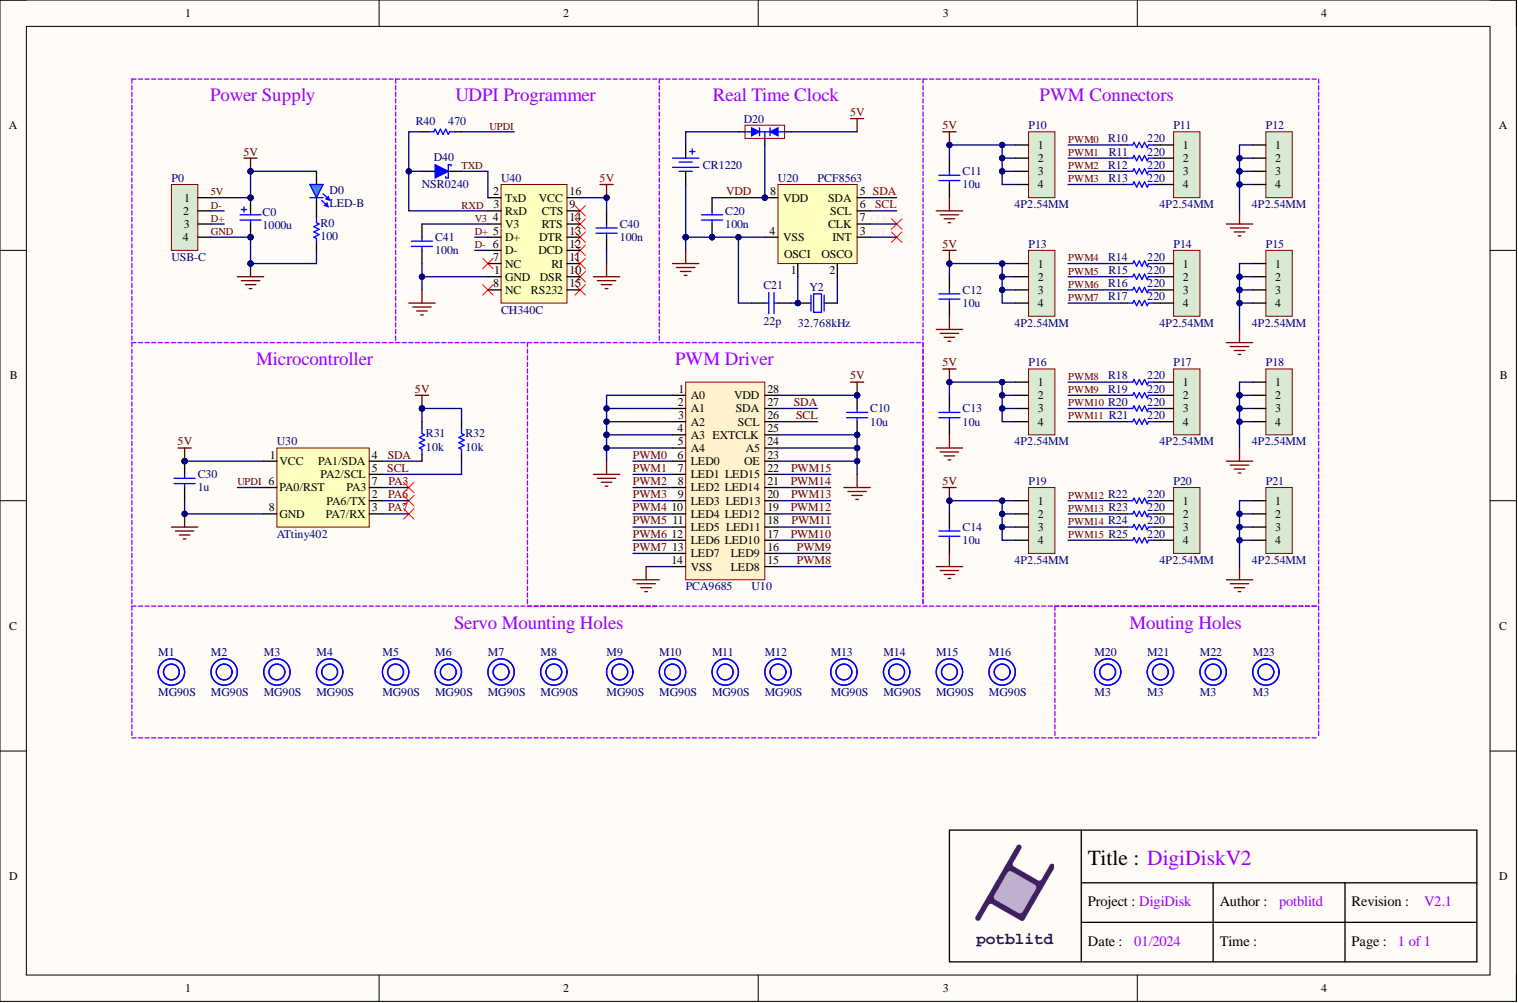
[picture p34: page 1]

2 | SD A
3 | SCL
5 | 2 4

potblitd | Title : DigiDisk V 2

Proje ct : DigiDis k | A uth or : p otblitd | Re visio n : f 1V 2 . 1

Date : 0 1 /2 0 2 4 | Tim e : | P a g e : 1 o

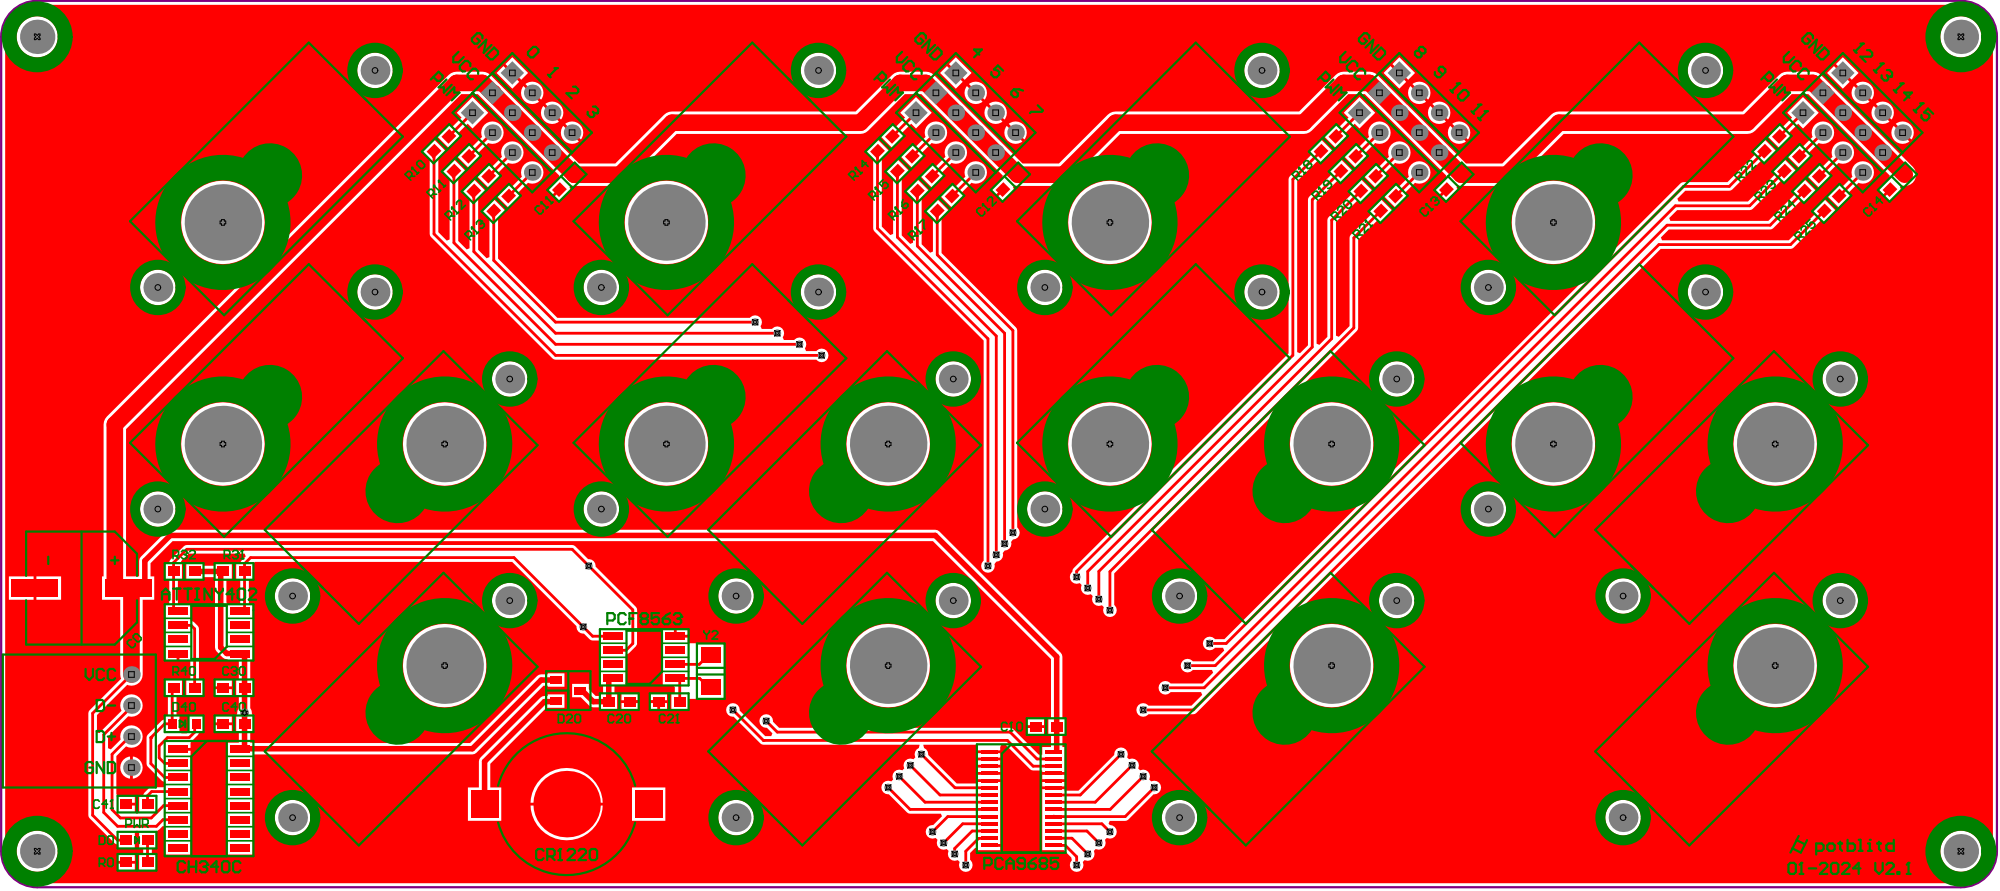
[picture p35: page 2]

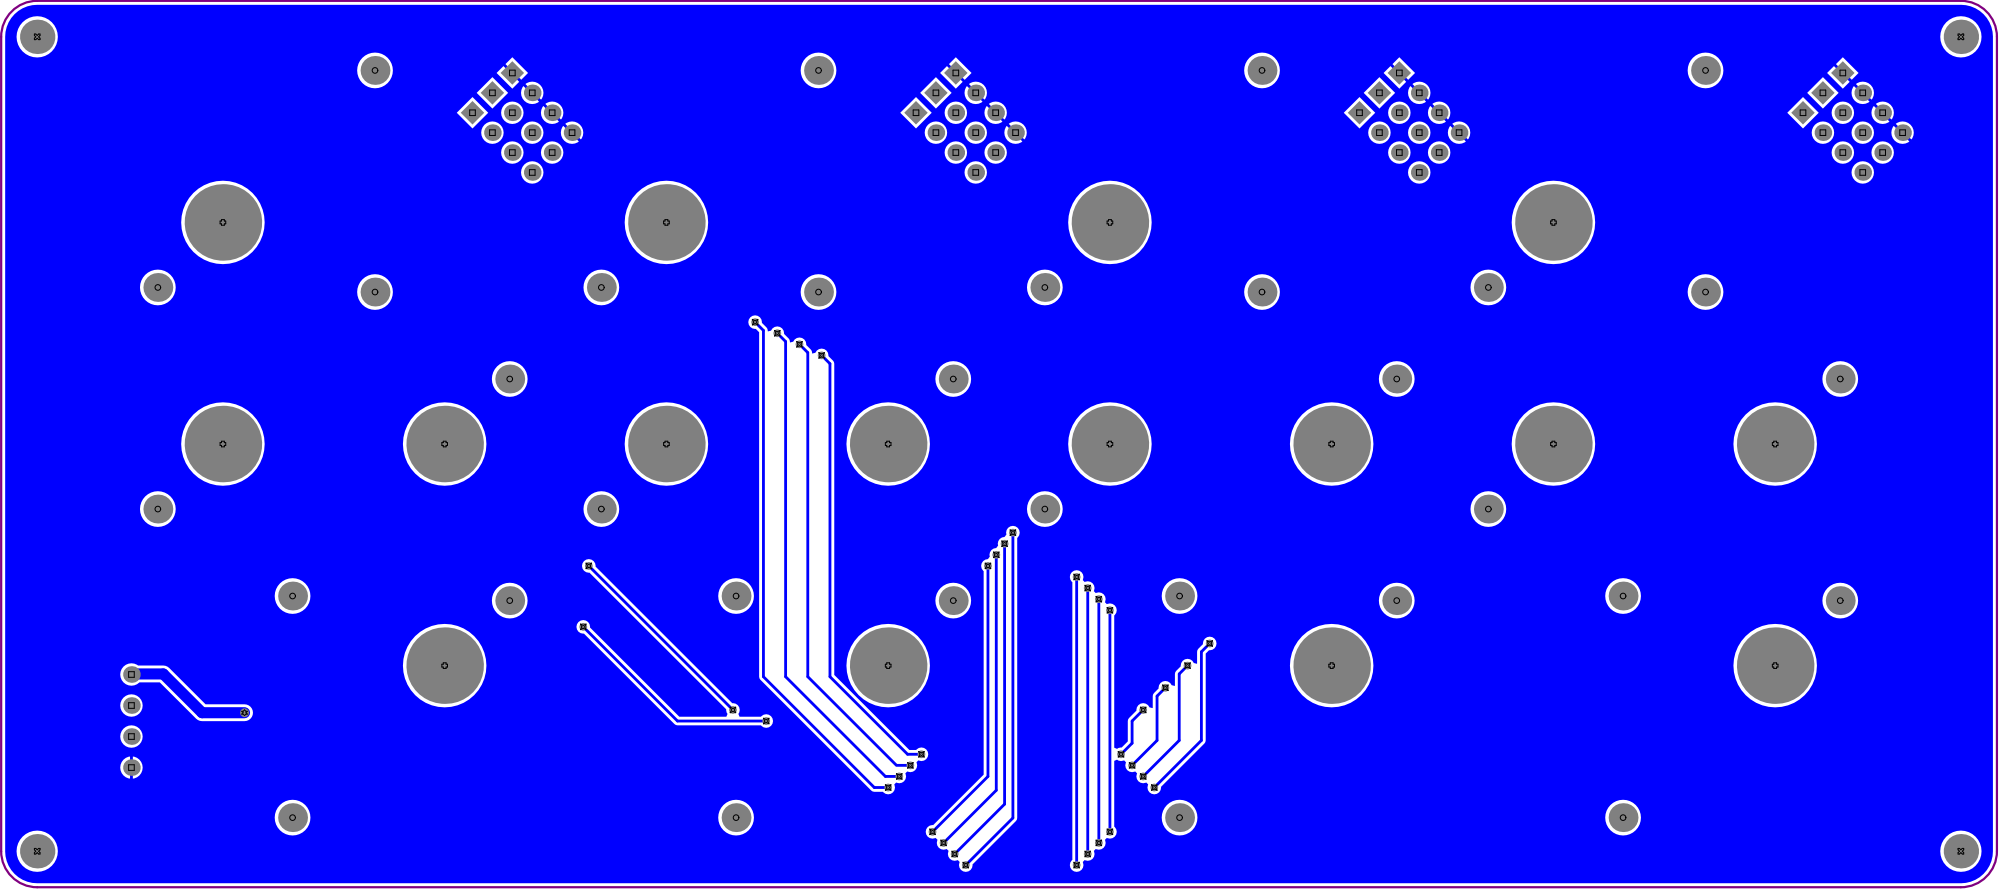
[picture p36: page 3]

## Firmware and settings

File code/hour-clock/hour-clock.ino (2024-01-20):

  
/*
DigiLog Clock Code
Microcontroller Wemos D1 mini (clone)
Make sure to have the CH340 driver installed
DS3231 library : https://github.com/NorthernWidget/DS3231/tree/master

*/

// include librairies
#include <DS3231.h>
#include <Adafruit_PWMServoDriver.h>
#include <Wire.h>
// init RTC variables
DS3231 rtc;
bool century = false;
bool h12Flag;
bool pmFlag;
byte hour;
byte disp1;
byte disp2;
// init driver variables
Adafruit_PWMServoDriver pwm = Adafruit_PWMServoDriver();
const int p0 = 105;
const int p90 = 320;
const int p180 = 525;

// FUNCTION
void safe_init(byte dispNum){
  // go to 0  all pointers seperately
  pwm.setPWM(2+4*(dispNum-1),0,p180);
  delay(500);
  pwm.setPWM(3+4*(dispNum-1),0,p0);
  delay(500);
  pwm.setPWM(1+4*(dispNum-1),0,p0);
  delay(500);
  pwm.setPWM(4+4*(dispNum-1),0,p90);
}

void safe_rest(byte dispNum){
  // go to 0  all pointers seperately
  pwm.setPWM(2+4*(dispNum-1),0,p90);
  delay(500);
  pwm.setPWM(3+4*(dispNum-1),0,p90);
  delay(500);
  pwm.setPWM(1+4*(dispNum-1),0,p90);
  delay(500);
  pwm.setPWM(4+4*(dispNum-1),0,p90);
}

void to_zero(byte digNum,byte dispNum){
  switch(digNum){
    case 2:
      // 2 -> 0
      pwm.setPWM(1+4*(dispNum-1),0,p0);
      pwm.setPWM(4+4*(dispNum-1),0,p90);
      delay(250);
      pwm.setPWM(3+4*(dispNum-1),0,p0);
      pwm.setPWM(2+4*(dispNum-1),0,p180);
      delay(750);
      break;
    case 3:
      // 3 -> 0
      pwm.setPWM(1+4*(dispNum-1),0,p0);
      pwm.setPWM(2+4*(dispNum-1),0,p180);
      delay(250);
      pwm.setPWM(3+4*(dispNum-1),0,p0);
      pwm.setPWM(4+4*(dispNum-1),0,p90);
      delay(750);
      break;
    case 5:
      // 5 -> 0
      pwm.setPWM(1+4*(dispNum-1),0,p0);
      pwm.setPWM(2+4*(dispNum-1),0,p180);
      delay(250);
      pwm.setPWM(3+4*(dispNum-1),0,p0);
      delay(250);
      pwm.setPWM(4+4*(dispNum-1),0,p90);
      delay(500);
      break;
  }
}

void show(byte digNum,byte dispNum){
  switch(digNum){
    case 0:
      // 9 -> 0
      pwm.setPWM(1+4*(dispNum-1),0,p0);
      pwm.setPWM(2+4*(dispNum-1),0,p180);
      pwm.setPWM(3+4*(dispNum-1),0,p0);
      pwm.setPWM(4+4*(dispNum-1),0,p90);
      delay(1000);
      break;
    case 1:
      // 0 -> 1
      pwm.setPWM(1+4*(dispNum-1),0,p180);
      pwm.setPWM(2+4*(dispNum-1),0,p90);
      pwm.setPWM(3+4*(dispNum-1),0,p0);
      pwm.setPWM(4+4*(dispNum-1),0,p0);
      delay(1000);
      break;
    case 2:
      // 1 -> 2
      pwm.setPWM(1+4*(dispNum-1),0,p90);
      pwm.setPWM(2+4*(dispNum-1),0,p180);
      pwm.setPWM(3+4*(dispNum-1),0,p90);
      pwm.setPWM(4+4*(dispNum-1),0,p180);
      delay(1000);
      break;
    case 3:
      // 2 -> 3
      pwm.setPWM(1+4*(dispNum-1),0,p90);
      pwm.setPWM(2+4*(dispNum-1),0,p90);
      pwm.setPWM(3+4*(dispNum-1),0,p90);
      pwm.setPWM(4+4*(dispNum-1),0,p90);
      delay(1000);
      break;
    case 4:
      // 3 ->4
      pwm.setPWM(1+4*(dispNum-1),0,p180);
      pwm.setPWM(2+4*(dispNum-1),0,p0);
      pwm.setPWM(3+4*(dispNum-1),0,p90);
      pwm.setPWM(4+4*(dispNum-1),0,p0);
      delay(1000);
      break;
    case 5:
      // 4 -> 5
      pwm.setPWM(1+4*(dispNum-1),0,p90);
      pwm.setPWM(2+4*(dispNum-1),0,p0);
      pwm.setPWM(4+4*(dispNum-1),0,p180);
      delay(500);
      pwm.setPWM(3+4*(dispNum-1),0,p180);
      delay(500);
      break;
    case 6:
      // 5 -> 6
      pwm.setPWM(1+4*(dispNum-1),0,p0);
      pwm.setPWM(2+4*(dispNum-1),0,p180);
      pwm.setPWM(3+4*(dispNum-1),0,p180);
      pwm.setPWM(4+4*(dispNum-1),0,p180);
      delay(1000);
      break;
    case 7:
      // 6 -> 7
      pwm.setPWM(2+4*(dispNum-1),0,p90);
      pwm.setPWM(3+4*(dispNum-1),0,p0);
      delay(250);
      pwm.setPWM(4+4*(dispNum-1),0,p0);
      delay(250);
      pwm.setPWM(1+4*(dispNum-1),0,p90);
      delay(500);
      break;
    case 8:
      // 7 -> 8
      pwm.setPWM(1+4*(dispNum-1),0,p0);
      pwm.setPWM(2+4*(dispNum-1),0,p180);
      pwm.setPWM(4+4*(dispNum-1),0,p90);
      delay(250);
      pwm.setPWM(3+4*(dispNum-1),0,p90);
      delay(750);
      break;
    case 9:
      // 8 -> 9
      pwm.setPWM(1+4*(dispNum-1),0,p0);
      pwm.setPWM(2+4*(dispNum-1),0,p90);
      pwm.setPWM(3+4*(dispNum-1),0,p90);
      pwm.setPWM(4+4*(dispNum-1),0,p90);
      delay(1000);
      break;
  }
}

void setup() {
  // setup d1 mini
  Serial.begin(9600);
  Wire.begin();
  pinMode(LED_BUILTIN, OUTPUT);
  // setup driver
  pwm.begin();
  pwm.setPWMFreq(50);
  // setup servo display
  safe_init(1);
  safe_init(2);
  delay(1000);
}

void loop() {
  // get time
  hour = rtc.getHour(h12Flag, pmFlag);
  Serial.print(hour); 
  Serial.print(" - ");
  // extract digits
  disp1 = hour%10;
  disp2 = floor(hour/10);
  Serial.print(disp2);
  Serial.print('-');
  Serial.print(disp1); 
  Serial.println();
  
  // show digits  
  if(hour == 0){
    to_zero(2,2);
    to_zero(3,1);
  } else {
    show(disp2,2);
    show(disp1,1);
  }
 
  // toggle LED
  digitalWrite(LED_BUILTIN, !digitalRead(LED_BUILTIN));
  delay(10*1000);
}

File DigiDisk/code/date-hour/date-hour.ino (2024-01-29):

// include librairies
#include "PCA9685.h"
#include <Rtc_Pcf8563.h>
#include <Wire.h>

// init driver 
PCA9685 pwm;
// init rtc and varibales
Rtc_Pcf8563 rtc;
byte hour;
byte day;
// init servo positions
const int p0 = 105;
const int p90 = 310;
const int p180 = 525;

// digit function
void set_digit(byte digit, byte disp){
  switch(digit){
    case 0:
      pwm.setChannelPWM(0+4*(disp-1), p90);
      pwm.setChannelPWM(1+4*(disp-1), p0);
      pwm.setChannelPWM(2+4*(disp-1), p180);
      pwm.setChannelPWM(3+4*(disp-1), p180);
      break;
    case 1:
      pwm.setChannelPWM(0+4*(disp-1), p180);
      pwm.setChannelPWM(1+4*(disp-1), p90);
      pwm.setChannelPWM(2+4*(disp-1), p180);
      pwm.setChannelPWM(3+4*(disp-1), p0);
      break;
    case 2:
      pwm.setChannelPWM(0+4*(disp-1), p90);
      pwm.setChannelPWM(1+4*(disp-1), p90);
      pwm.setChannelPWM(2+4*(disp-1), p0);
      pwm.setChannelPWM(3+4*(disp-1), p180);
      break;
    case 3:
      pwm.setChannelPWM(0+4*(disp-1), p90);
      pwm.setChannelPWM(1+4*(disp-1), p90);
      pwm.setChannelPWM(2+4*(disp-1), p90);
      pwm.setChannelPWM(3+4*(disp-1), p90);
      break;
    case 4:
      pwm.setChannelPWM(0+4*(disp-1), p180);
      pwm.setChannelPWM(1+4*(disp-1), p0);
      pwm.setChannelPWM(2+4*(disp-1), p90);
      pwm.setChannelPWM(3+4*(disp-1), p0);
      break;
    case 5:
      pwm.setChannelPWM(0+4*(disp-1), p0);
      pwm.setChannelPWM(1+4*(disp-1), p0);
      pwm.setChannelPWM(2+4*(disp-1), p90);
      pwm.setChannelPWM(3+4*(disp-1), p90);
      break;
    case 6:
      pwm.setChannelPWM(0+4*(disp-1), p0);
      pwm.setChannelPWM(1+4*(disp-1), p0);
      pwm.setChannelPWM(2+4*(disp-1), p90);
      pwm.setChannelPWM(3+4*(disp-1), p180);
      break;
    case 7:
      pwm.setChannelPWM(0+4*(disp-1), p90);
      pwm.setChannelPWM(1+4*(disp-1), p90);
      pwm.setChannelPWM(2+4*(disp-1), p180);
      pwm.setChannelPWM(3+4*(disp-1), p0);
      break;
    case 8:
      pwm.setChannelPWM(0+4*(disp-1), p90);
      pwm.setChannelPWM(1+4*(disp-1), p0);
      pwm.setChannelPWM(2+4*(disp-1), p90);
      pwm.setChannelPWM(3+4*(disp-1), p180);
      break;
    case 9:
      pwm.setChannelPWM(0+4*(disp-1), p90);
      pwm.setChannelPWM(1+4*(disp-1), p0);
      pwm.setChannelPWM(2+4*(disp-1), p90);
      pwm.setChannelPWM(3+4*(disp-1), p90);
      break;
  }
}

void setup() {
  // setup i2c
  Wire.begin();
  // setup driver
  pwm.resetDevices();
  pwm.init();
  pwm.setPWMFrequency(50);
  // setup servo display
  set_digit(0,1);
  set_digit(0,2);
  set_digit(0,3);
  set_digit(0,4);
  delay(1000);
}

void loop() {
  // get time
  hour = rtc.getHour();
  day = rtc.getDay();
  // show digits
  set_digit(hour%10,1);
  set_digit(floor(hour/10),2);
  set_digit(day%10,3);
  set_digit(floor(day/10),4);

  delay(1000);
  
}

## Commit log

2024-01-06 add arduino code
2024-01-08 add 3d models
    [front-plate.stl, mounting-plate.stl, pointers.stl]
2024-01-08 update servo arrangement
2024-01-17 add pcb files and gif
    [digidisk.PcbDoc, digidisk.SchDoc]
2024-01-17 add schamtics
    [digidisk.SchDoc]
2024-01-22 update schematics
2024-01-26 add pcb design files
    [DigiDisk-disks.PcbDoc, digidisk.PcbDoc, digidisk.SchDoc]
2024-01-27 add front plate image
